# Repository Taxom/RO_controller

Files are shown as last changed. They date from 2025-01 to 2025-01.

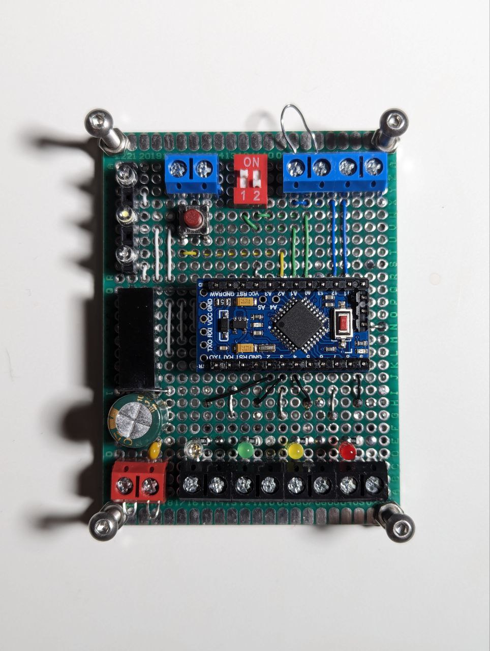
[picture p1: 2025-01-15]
photos/photo_2024-03-21_01-51-25.jpg

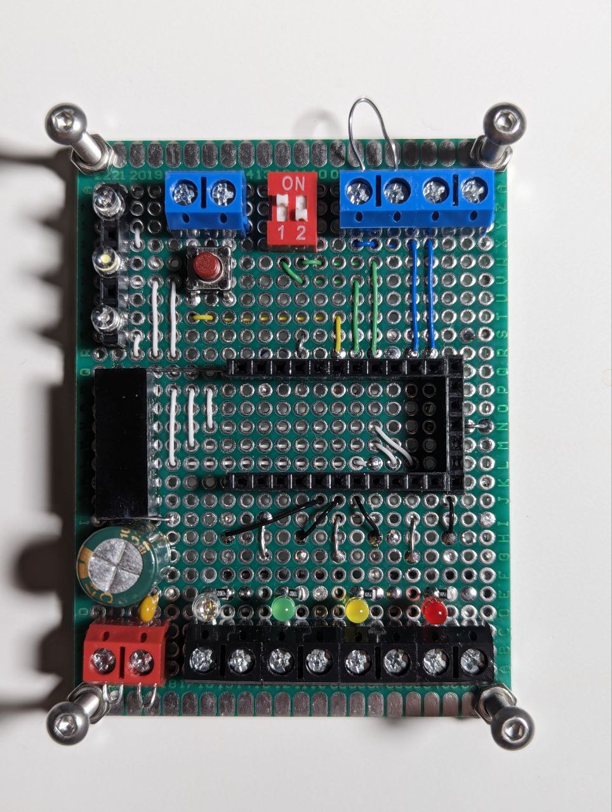
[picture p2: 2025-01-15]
photos/photo_2024-03-21_01-51-22.jpg

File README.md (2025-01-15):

# RO Controller

**RO Controller** is an Arduino-based project designed to manage a reverse osmosis system. The controller automatically regulates water supply, cleans filters, and monitors the tank status.

## Features

- **Pressure Sensors**:
  - Monitor the availability of incoming water and tank fullness.
- **Automatic Valve Control**:
  - Manage water input, flushing, and draining.
- **Status Indication**:
  - LEDs display the current operating mode (filtering, flushing, water status).
- **Periodic Filter Flushing**:
  - Configurable flushing intervals: 6, 12, or 24 hours.

## Components and Pin Configuration

- **Input Sensors**:
  - Water availability sensor: pin `12`.
  - Tank level sensor: pin `11`.
- **Outputs for Control**:
  - Water input valve: pin `2`.
  - Flushing valve: pin `4`.
  - Pump: pin `3`.
  - Drain valve: pin `9`.
- **Indicators**:
  - Filtering LED: pin `6`.
  - Flushing LED: pin `7`.
  - Water status LED: pin `5`.
- **Flushing Button**:
  - Manual flushing activation button: pin `A2`.

## Configurable Parameters

- **Flushing Intervals**:
  - 6 hours, 12 hours, or 24 hours.
- **Flushing Duration**:
  - 15 seconds.

## How to Use

1. Connect components according to the specified pin configuration.
2. Upload the code to the Arduino controller (e.g., Arduino Pro Mini).
3. Power on the system to start automatic operation.
4. For manual flushing, press the button connected to pin `A2`.

## Author

The project is developed by **Maxim Pivovarov**.
2023

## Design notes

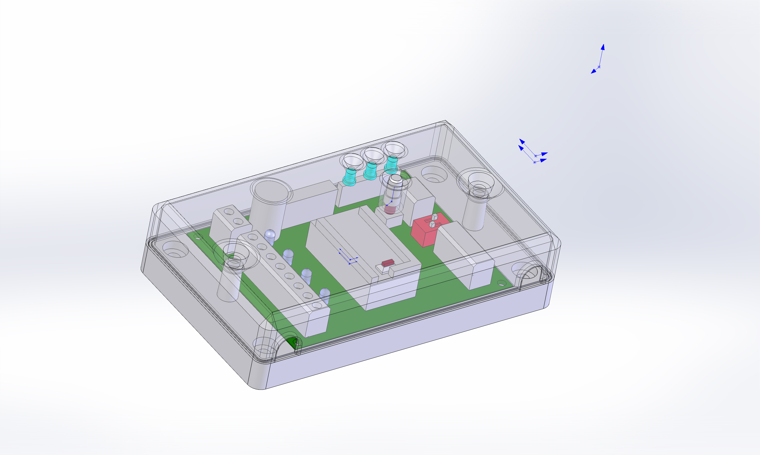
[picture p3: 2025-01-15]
photos/Contrtroller_unit_v2.JPG

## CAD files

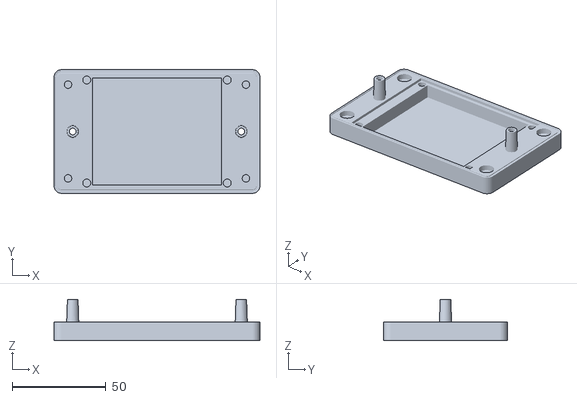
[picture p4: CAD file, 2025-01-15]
cad/Contrtroller_unit_base_v2.STL
110.0 x 66.0 x 22.0

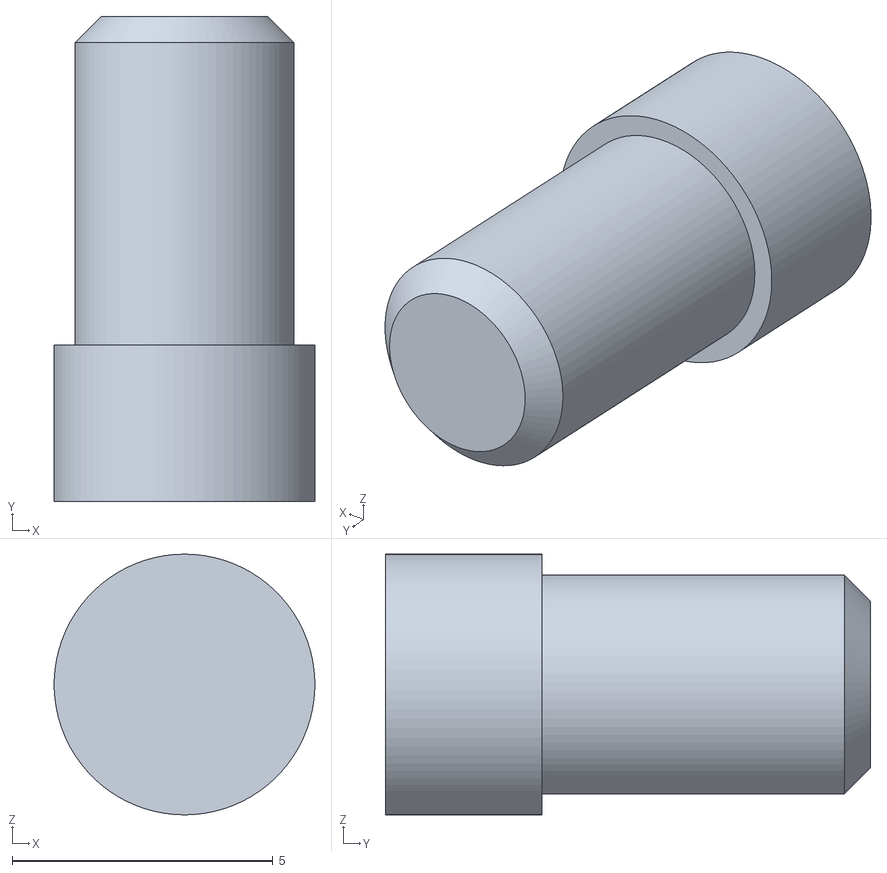
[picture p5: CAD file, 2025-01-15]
cad/button_pin_v2.STL
5.00 x 9.30 x 5.00

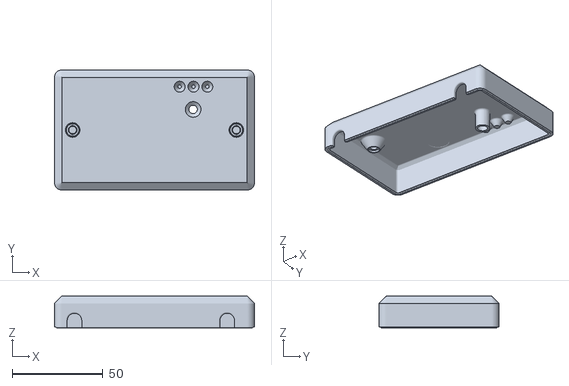
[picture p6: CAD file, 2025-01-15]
cad/Contrtroller_unit_cover_v2.STL
110.0 x 66.0 x 17.4

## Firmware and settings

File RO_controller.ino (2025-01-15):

/*
-------------------------------
RO-filter_control_v0.6
@Pivovarov Maxim
25/03/2024
Arduino_mini_pro
-------------------------------
*/

const int INPUT_PRESSURE_SENSOR_PIN = 12; // LOW if water is available 
const int OUTPUT_PRESSURE_SENSOR_PIN = 11; // HIGH if the tank is full
const int FLUSH_SET1_PIN = A0;
const int FLUSH_SET2_PIN = A1;
const int BUTTON_FLUSH = A2; // active LOW
// For all outputs, active is HIGH
const int INPUT_VALVE_PIN = 2; 
const int FLUSH_VALVE_PIN = 4;
const int DRAIN_VALVE_PIN = 9;
const int PUMP_PIN = 3;
const int FILTERING_LED_PIN = 6;
const int FLUSH_LED_PIN = 7;
const int WATER_LED_PIN = 5;


const unsigned long FLUSH_PERIOD_6_HOURS = 6UL * 60UL * 60UL * 1000UL;   // 6 hours in milliseconds
const unsigned long FLUSH_PERIOD_12_HOURS = 12UL * 60UL * 60UL * 1000UL; // 12 hours in milliseconds
const unsigned long FLUSH_PERIOD_24_HOURS = 24UL * 60UL * 60UL * 1000UL; // 24 hours in milliseconds


const int FLUSH_DELAY = 15*1000; // duration of periodic flushing 
const int PREFLUSH_DELAY = 10*1000; // duration of pre-production flushing
const int POSTFLUSH_DELAY = 10*1000; // duration of post-production flushing
const int POSTDREIN_DELAY = 5*1000; // duration of permeate pressure release
const int PREDRAINE_DELAY = 30*1000; // duration of initial permeate release
const int PRESSURE_RELEASE_DELAY = 3*1000; // duration of pressure release after pump shutdown
const int HYSTERESIS = 10*1000; // duration of operation after tank full sensor triggers
const int BOOT_FLASH = 5; // boot delay, 1 flash 0.25+0.25 seconds

unsigned long previousFlash = 0;
unsigned long lastFlushTime = 0;
unsigned long flushPeriod = 0;
// bool waterInput = 0 // Instead of a variable, use the WATER_LED_PIN port; if water is available, then HIGH (on)


// Function declarations
void setFlushPeriod();
void startWaterPreparation();
void flushMembrane();
bool checkInputPressure();
void delayWithoutBlocking(unsigned long ms);


void setup() {

  // Pressure sensors
  pinMode(INPUT_PRESSURE_SENSOR_PIN, INPUT_PULLUP);
  pinMode(OUTPUT_PRESSURE_SENSOR_PIN, INPUT_PULLUP);
  // Jumpers and flush button
  pinMode(FLUSH_SET1_PIN, INPUT_PULLUP);
  pinMode(FLUSH_SET2_PIN, INPUT_PULLUP); 
  pinMode(BUTTON_FLUSH, INPUT_PULLUP);
  // Valves and pump
  pinMode(INPUT_VALVE_PIN, OUTPUT);
  pinMode(FLUSH_VALVE_PIN, OUTPUT);
  pinMode(DRAIN_VALVE_PIN, OUTPUT);
  pinMode(PUMP_PIN, OUTPUT);
  // Status indicators
  pinMode(FILTERING_LED_PIN, OUTPUT);
  pinMode(FLUSH_LED_PIN, OUTPUT);
  pinMode(WATER_LED_PIN, OUTPUT);

  pinMode(LED_BUILTIN, OUTPUT);

  // Set all outputs to LOW
  digitalWrite(INPUT_VALVE_PIN, LOW);
  digitalWrite(FLUSH_VALVE_PIN, LOW);
  digitalWrite(DRAIN_VALVE_PIN, LOW);
  digitalWrite(PUMP_PIN, LOW);
  digitalWrite(FILTERING_LED_PIN, LOW);
  digitalWrite(FLUSH_LED_PIN, LOW);
  digitalWrite(WATER_LED_PIN, LOW);
  
  for (int i = 0; i<BOOT_FLASH; i++){
    digitalWrite (LED_BUILTIN, HIGH);
    delay(250);
    digitalWrite (LED_BUILTIN, LOW);
    delay(250);
  }
}

void loop() {
  // Check jumper settings
  setFlushPeriod(); 


  // Sit here and blink LED_BUILTIN while there is no water
  while (digitalRead(INPUT_PRESSURE_SENSOR_PIN)){
    digitalWrite(WATER_LED_PIN, LOW);
    unsigned long currentMillis = millis();

    if (currentMillis - previousFlash >= 1000) { 
        previousFlash = currentMillis;
        int ledState = digitalRead(LED_BUILTIN);
        digitalWrite(LED_BUILTIN, !ledState);
    }

  }


  // On first start or if water appears
  if (!digitalRead(WATER_LED_PIN) && (!digitalRead(INPUT_PRESSURE_SENSOR_PIN))){
    digitalWrite(WATER_LED_PIN, HIGH);
    digitalWrite(LED_BUILTIN, LOW);
	  flushMembrane(); // Start flushing
  }  


  // If it's time for flushing and water is available
  if (flushPeriod && (millis() - lastFlushTime >= flushPeriod) && digitalRead(WATER_LED_PIN) && (!digitalRead(INPUT_PRESSURE_SENSOR_PIN))) { 
    flushMembrane(); // Start flushing
  }
  

  // Flush button pressed
  if (!digitalRead(BUTTON_FLUSH) && digitalRead(WATER_LED_PIN) && !digitalRead(INPUT_PRESSURE_SENSOR_PIN)){
	  flushMembrane(); // Start flushing
  }
  

  // If the tank is empty and water is available  
  if (digitalRead(WATER_LED_PIN) && (!digitalRead(OUTPUT_PRESSURE_SENSOR_PIN))){ 
	  startWaterPreparation(); // Start filtration
  }

}


// Check jumpers and set flushing time
void setFlushPeriod() {   
  bool set1 = !digitalRead(FLUSH_SET1_PIN);
  bool set2 = !digitalRead(FLUSH_SET2_PIN);

  if (set1 && !set2) {
    flushPeriod = FLUSH_PERIOD_6_HOURS;
  } else if (!set1 && set2) {
    flushPeriod = FLUSH_PERIOD_12_HOURS;
  } else if (set1 && set2) {
    flushPeriod = FLUSH_PERIOD_24_HOURS;
  } else {
    flushPeriod = 0; // No flushing if no jumpers are set
  }
}


// Filtration function
void startWaterPreparation() {    
	// Turn on the "filtration" indicator
	digitalWrite(FILTERING_LED_PIN, HIGH);
	// Open all valves and turn on the pump
  digitalWrite(INPUT_VALVE_PIN, HIGH);
  digitalWrite(FLUSH_VALVE_PIN, HIGH);
  digitalWrite(DRAIN_VALVE_PIN, HIGH);
  digitalWrite(PUMP_PIN, HIGH);
	// Pre-flushing
  delayWithoutBlocking(PREFLUSH_DELAY);
	// After the first delay, close the flush valve
  digitalWrite(FLUSH_VALVE_PIN, LOW);
	// Let the initial permeate drain
  delayWithoutBlocking(PREDRAINE_DELAY);
	// Close the permeate drain valve
  digitalWrite(DRAIN_VALVE_PIN, LOW);
  // Wait for the tank to fill  
  while (!digitalRead(OUTPUT_PRESSURE_SENSOR_PIN) && (digitalRead(WATER_LED_PIN))) {  
	  // Check input pressure
    if (checkInputPressure()){        
      return;    
	  } 
  } 
  // Increase pressure for hysteresis
  delayWithoutBlocking(HYSTERESIS);  
	// Finish filtration with flushing if available
  if (digitalRead(WATER_LED_PIN)){
    digitalWrite(FLUSH_VALVE_PIN, HIGH);   
	  // Flush 
    delayWithoutBlocking(POSTFLUSH_DELAY);
	  // Turn off the pump and close the input valve	
    digitalWrite(PUMP_PIN, LOW);
    digitalWrite(INPUT_VALVE_PIN, LOW);
    // Wait for pressure release on the input
	  delayWithoutBlocking(PRESSURE_RELEASE_DELAY);
	  // Close the flush valve
    digitalWrite(FLUSH_VALVE_PIN, LOW);  
    // Reset periodic flush timer
    lastFlushTime = millis();	  
    // Turn off the "filtration" indicator and exit
    digitalWrite(FILTERING_LED_PIN, LOW);
  }
}


// Membrane flushing function
void flushMembrane() {
  // Turn on the "flushing" indicator
  digitalWrite(FLUSH_LED_PIN, HIGH);
  // Open all valves and start the pump
  digitalWrite(INPUT_VALVE_PIN, HIGH);
  digitalWrite(FLUSH_VALVE_PIN, HIGH);
  digitalWrite(DRAIN_VALVE_PIN, HIGH);
  digitalWrite(PUMP_PIN, HIGH);
  // Flushing
  delayWithoutBlocking(FLUSH_DELAY);
  // Close valves and turn off the pump
  digitalWrite(PUMP_PIN, LOW);
  digitalWrite(INPUT_VALVE_PIN, LOW);
  digitalWrite(DRAIN_VALVE_PIN, LOW);
  // Wait for pressure release on the input 
  delayWithoutBlocking(PRESSURE_RELEASE_DELAY);
  // Close the flush valve
  digitalWrite(FLUSH_VALVE_PIN, LOW);  
  // Reset periodic flush timer
  lastFlushTime = millis();
  digitalWrite(FLUSH_LED_PIN, LOW);	
}

// Function to check pressure and protect the pump
bool checkInputPressure() {
  if (digitalRead(INPUT_PRESSURE_SENSOR_PIN)) {  // If water pressure is lost, start pump protection procedure
    digitalWrite(PUMP_PIN, LOW); 
    digitalWrite(INPUT_VALVE_PIN, LOW);
    digitalWrite(WATER_LED_PIN, LOW);
    digitalWrite(FILTERING_LED_PIN, LOW);
    digitalWrite(FLUSH_LED_PIN, LOW);
    // Open flush and drain valves to release pressure
    digitalWrite(FLUSH_VALVE_PIN, HIGH);
    digitalWrite(DRAIN_VALVE_PIN, HIGH);    
    // Wait for pressure release   
	  delay(PRESSURE_RELEASE_DELAY);
	  // Close flush and drain valves
    digitalWrite(FLUSH_VALVE_PIN, LOW);
    digitalWrite(DRAIN_VALVE_PIN, LOW);
	  return true;
  }  
  return false;
}

void delayWithoutBlocking(unsigned long ms) {  
  unsigned long start = millis();  
  while ((digitalRead(WATER_LED_PIN)) && (millis() - start < ms)) {
	  if (checkInputPressure()){ // Check pressure during waiting
    break;
	  }  
  }
}
